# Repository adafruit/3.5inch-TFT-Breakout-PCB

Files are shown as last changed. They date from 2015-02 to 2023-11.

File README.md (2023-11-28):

# Adafruit 3.5 inch TFT LCD Display Breakout PCB

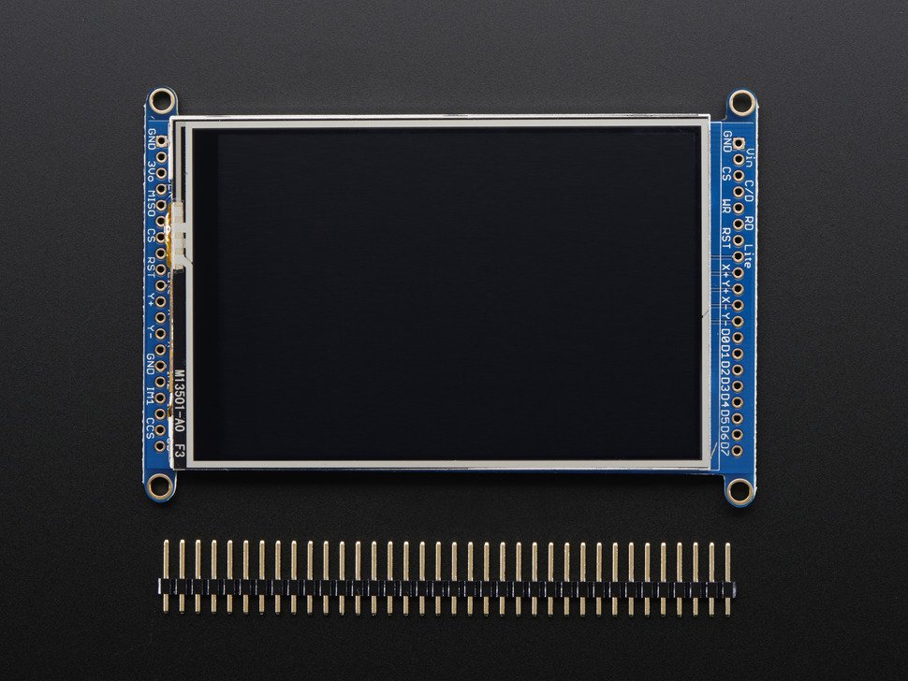
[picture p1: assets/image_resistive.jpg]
<a href="http://www.adafruit.com/products/2050"><br/>
Click here to purchase one from the Adafruit shop</a>

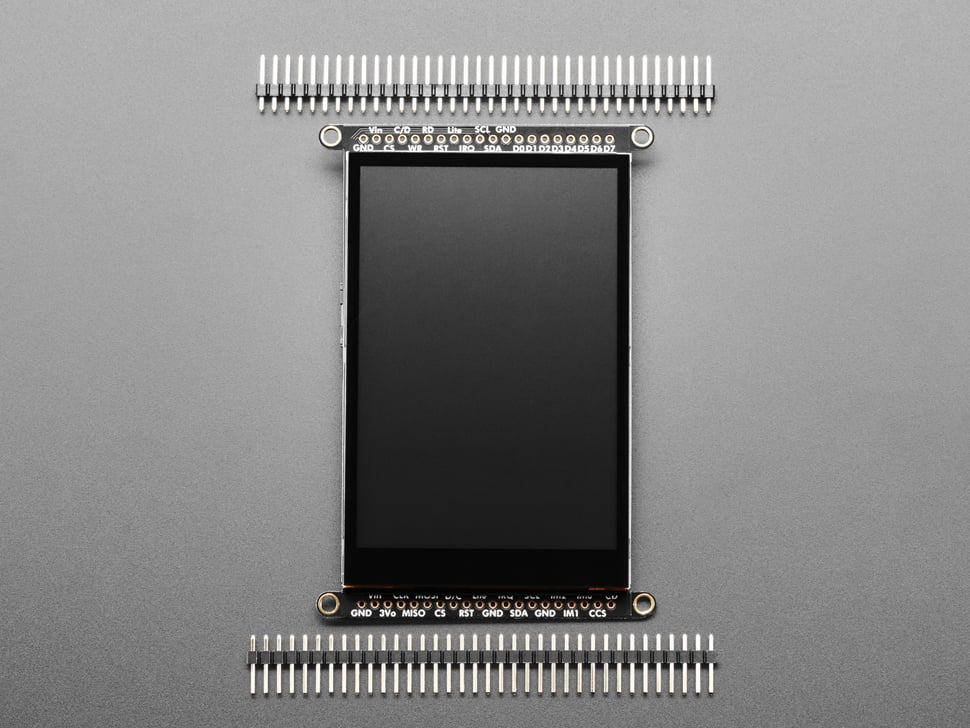
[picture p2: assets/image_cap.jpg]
<a href="http://www.adafruit.com/products/5846"><br/>
Click here to purchase one from the Adafruit shop</a>

Adafruit 3.5" 18-bit color TFT LCD display with microSD card breakout

This TFT display is big (3.5" diagonal) bright (6 white-LED backlight) and colorful! 480x320 pixels with individual RGB pixel control, this has way more resolution than a black and white 128x64 display, and double our 2.8" TFT. 

There are two version of this display: one has a resistive touchscreen attached to it and the other has a capacitive touchscreen attached.

This display has a controller built into it with RAM buffering, so that almost no work is done by the microcontroller. The display can be used in two modes: 8-bit or SPI. For 8-bit mode, you'll need 8 digital data lines and 4 or 5 digital control lines to read and write to the display (12 lines total). SPI mode requires only 5 pins total (SPI data in, data out, clock, select, and d/c) but is slower than 8-bit mode. In addition, 4 pins are required for the touch screen (2 digital, 2 analog) or you can purchase and use our resistive touchscreen controller (not included) to use I2C or SPI.

These are the Eagle CAD files for the Adafruit 3.5" 18-bit color TFT LCD display with microSD card breakout:
  ----> https://www.adafruit.com/products/2050

and the Adafruit 3.5" TFT 320x480 with Capacitive Touch Breakout Board - EYESPI
  ----> https://www.adafruit.com/products/5846

### License

Adafruit invests time and resources providing this open source design, please support Adafruit and open-source hardware by purchasing products from [Adafruit](https://www.adafruit.com)!

All text above must be included in any redistribution

Designed by Limor Fried/Ladyada for Adafruit Industries.
Creative Commons Attribution/Share-Alike, all text above must be included in any redistribution. 
See license.txt for additional information.

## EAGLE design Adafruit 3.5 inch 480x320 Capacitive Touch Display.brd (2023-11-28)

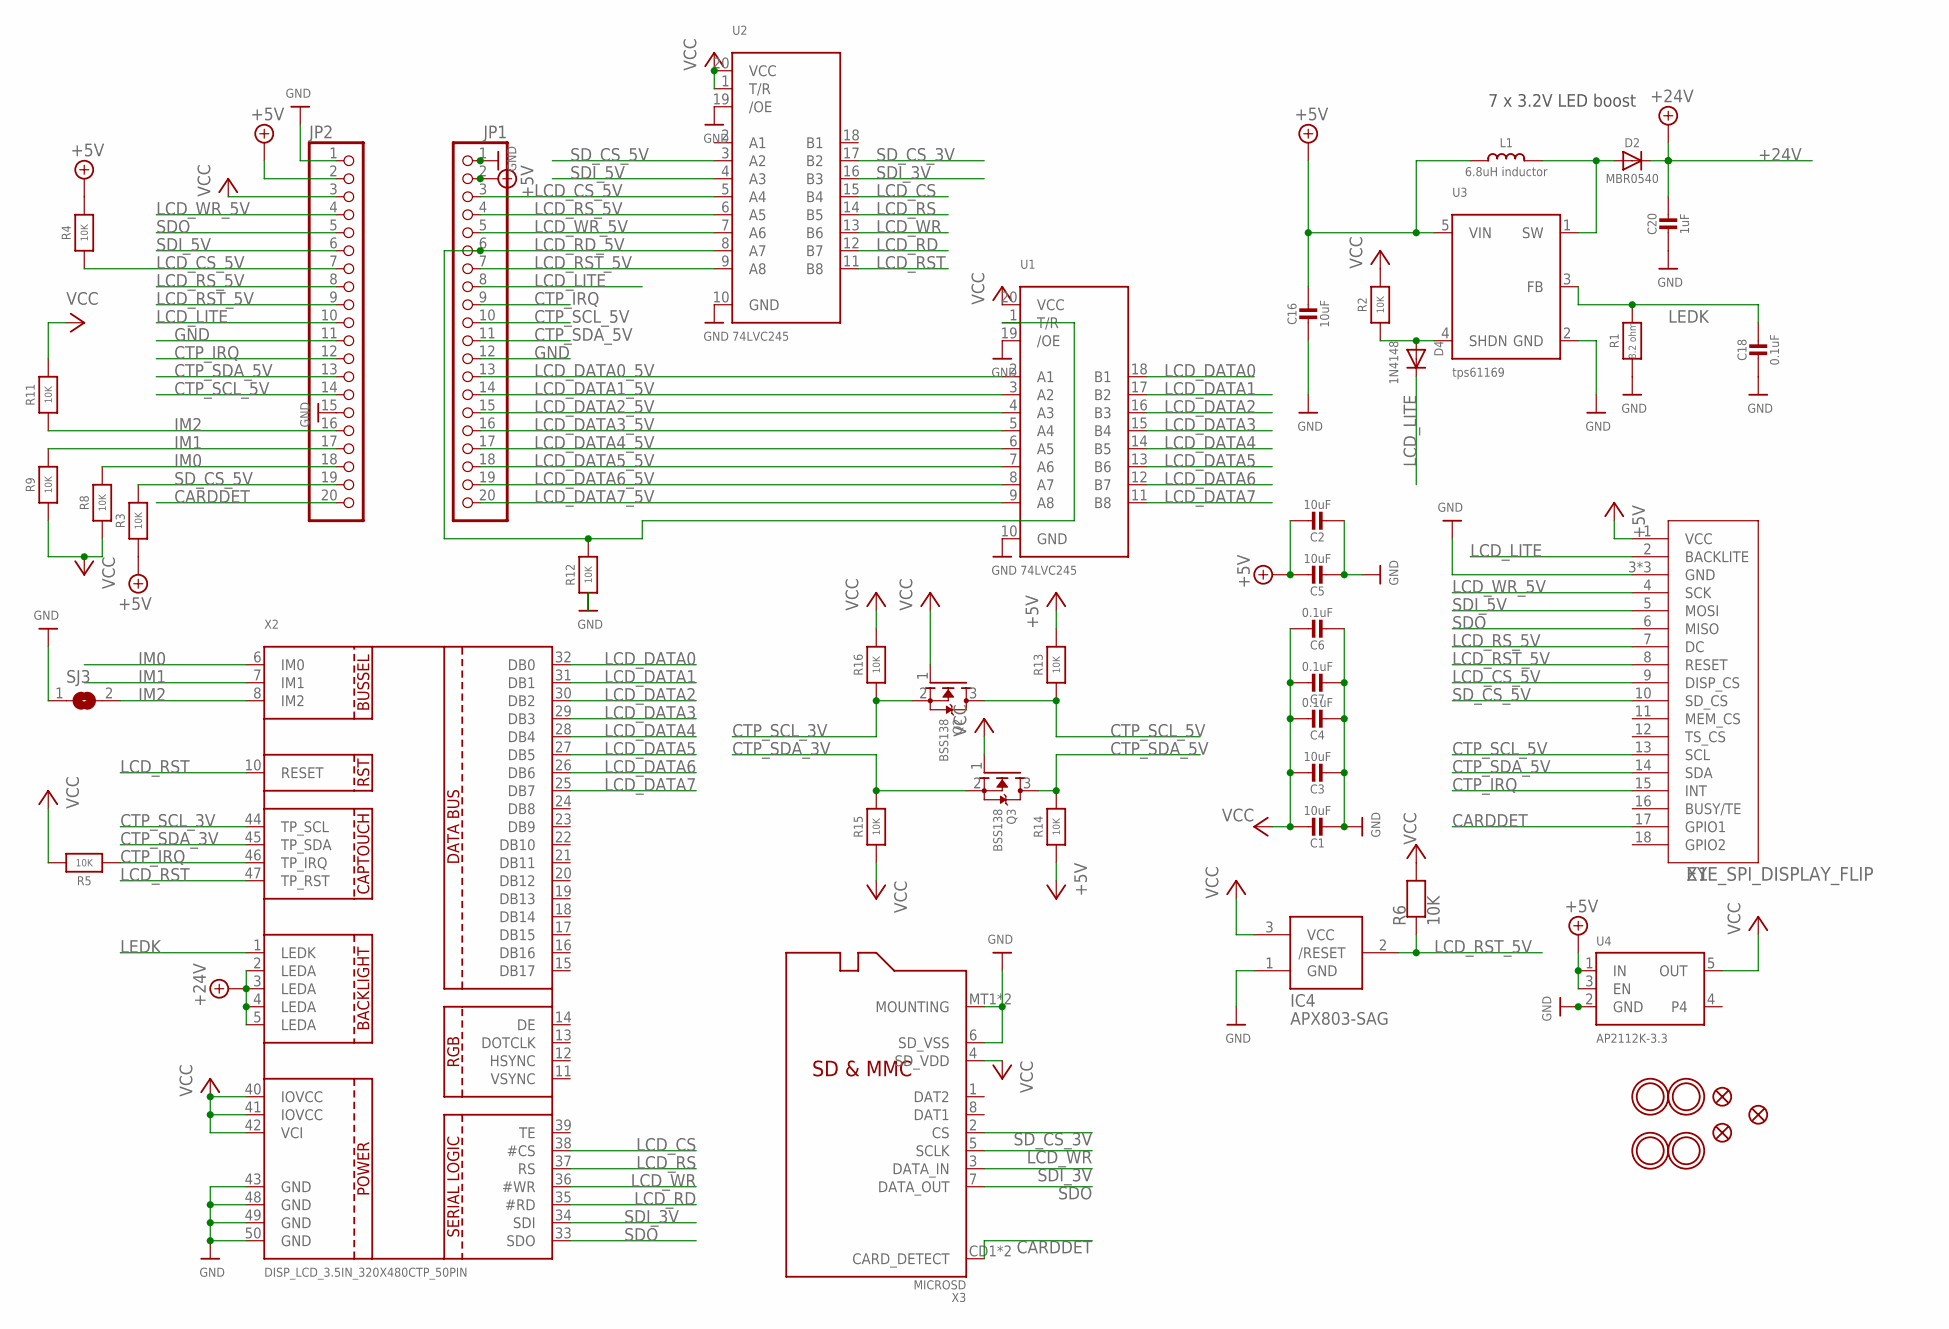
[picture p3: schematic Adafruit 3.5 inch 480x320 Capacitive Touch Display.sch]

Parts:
C1, C2, C3, C5, C16: 10uF; 0805-NO
C4, C6, C7, C18: 0.1uF; 0603-NO
C20: 1uF; 0805-NO
D2: MBR0540; SOD-123
D4: 1N4148; SOD-323F
IC4: APX803-SAG; SOT23
JP1, JP2: HEADER-1X20ROUND; 1X20_ROUND
L1: 6.8uH inductor; INDUCTOR_5X5MM_NR5040_NOTHERMALS
Q2, Q3: BSS138; SOT23-WIDE
R1: 8.2 ohm; 0603-NO
R2, R3, R4, R5, R6, R8, R9, R11, R12, R13, R14, R15, R16: 10K; 0603-NO
SJ3: SOLDERJUMPER; SOLDERJUMPER_ARROW_NOPASTE
U1, U2: 74LVC245; TSSOP20
U3: tps61169; SC70-5
U4: AP2112K-3.3; SOT23-5
U$7, U$15, U$16, U$17: MOUNTINGHOLE3.0THIN; MOUNTINGHOLE_3.0_PLATEDTHIN
U$9, U$11, U$23: FIDUCIAL_1MM
X1: EYE_SPI_DISPLAY_FLIP; EYE_SPI_DISPLAY_BOTCONTACT
X2: DISP_LCD_3.5IN_320X480CTP_50PIN; TFT_3.5IN_320X480_50PIN
X3: MICROSD

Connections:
+5V: C2.1, C5.1, C16.1, JP1.2, JP2.2, L1.P$1 (1), R3.1, R4.2, R13.2, R14.1, U3.5 (VIN), U4.1 (IN), U4.3 (EN), X1.1 (VCC)
+24V: C20.1, D2.C, X2.2 (LEDA), X2.3 (LEDA), X2.4 (LEDA), X2.5 (LEDA)
CARDDET: JP2.20, X1.17 (GPIO1), X3.CD1 (CARD_DETECT), X3.CD2 (CARD_DETECT)
CTP_IRQ: JP1.9, JP2.12, R5.1, X1.15 (INT), X2.46 (TP_IRQ)
CTP_SCL_3V: Q2.2 (S), R16.1, X2.44 (TP_SCL)
CTP_SCL_5V: JP1.10, JP2.14, Q2.3 (D), R13.1, X1.13 (SCL)
CTP_SDA_3V: Q3.2 (S), R15.2, X2.45 (TP_SDA)
CTP_SDA_5V: JP1.11, JP2.13, Q3.3 (D), R14.2, X1.14 (SDA)
GND: C1.2, C2.2, C3.2, C4.2, C5.2, C6.2, C7.2, C16.2, C18.2, C20.2, IC4.1 (GND), JP1.1, JP1.12, JP2.1, JP2.11, JP2.15, R1.1, R12.1, SJ3.1, U1.10 (GND), U1.19 (/OE), U2.10 (GND), U2.19 (/OE), U3.2 (GND), U4.2 (GND), X1.3 (GND), X1.SUPPORT1 (GND), X1.SUPPORT2 (GND), X2.43 (GND), X2.48 (GND), X2.49 (GND), X2.50 (GND), X3.6 (SD_VSS), X3.MT1 (MOUNTING), X3.MT2 (MOUNTING)
IM0: JP2.18, R8.2, X2.6 (IM0)
IM1: JP2.17, R9.2, X2.7 (IM1)
IM2: JP2.16, R11.1, SJ3.2, X2.8 (IM2)
LCD_CS: U2.15 (B4), X2.38 (#CS)
LCD_CS_5V: JP1.3, JP2.7, R4.1, U2.5 (A4), X1.9 (DISP_CS)
LCD_DATA0: U1.18 (B1), X2.32 (DB0)
LCD_DATA0_5V: JP1.13, U1.2 (A1)
LCD_DATA1: U1.17 (B2), X2.31 (DB1)
LCD_DATA1_5V: JP1.14, U1.3 (A2)
LCD_DATA2: U1.16 (B3), X2.30 (DB2)
LCD_DATA2_5V: JP1.15, U1.4 (A3)
LCD_DATA3: U1.15 (B4), X2.29 (DB3)
LCD_DATA3_5V: JP1.16, U1.5 (A4)
LCD_DATA4: U1.14 (B5), X2.28 (DB4)
LCD_DATA4_5V: JP1.17, U1.6 (A5)
LCD_DATA5: U1.13 (B6), X2.27 (DB5)
LCD_DATA5_5V: JP1.18, U1.7 (A6)
LCD_DATA6: U1.12 (B7), X2.26 (DB6)
LCD_DATA6_5V: JP1.19, U1.8 (A7)
LCD_DATA7: U1.11 (B8), X2.25 (DB7)
LCD_DATA7_5V: JP1.20, U1.9 (A8)
LCD_LITE: D4.C, JP1.8, JP2.10, X1.2 (BACKLITE)
LCD_RD: U2.12 (B7), X2.35 (#RD)
LCD_RD_5V: JP1.6, R12.2, U1.1 (T/R), U2.8 (A7)
LCD_RS: U2.14 (B5), X2.37 (RS)
LCD_RST: U2.11 (B8), X2.10 (RESET), X2.47 (TP_RST)
LCD_RST_5V: IC4.2 (/RESET), JP1.7, JP2.9, R6.1, U2.9 (A8), X1.8 (RESET)
LCD_RS_5V: JP1.4, JP2.8, U2.6 (A5), X1.7 (DC)
LCD_WR: U2.13 (B6), X2.36 (#WR), X3.5 (SCLK)
LCD_WR_5V: JP1.5, JP2.4, U2.7 (A6), X1.4 (SCK)
LEDK: C18.1, R1.2, U3.3 (FB), X2.1 (LEDK)
unnamed: D2.A, L1.P$2 (2), U3.1 (SW)
SDI_3V: U2.16 (B3), X2.34 (SDI), X3.3 (DATA_IN)
SDI_5V: JP2.6, U2.4 (A3), X1.5 (MOSI)
SDO: JP2.5, X1.6 (MISO), X2.33 (SDO), X3.7 (DATA_OUT)
SD_CS_3V: U2.17 (B2), X3.2 (CS)
SD_CS_5V: JP2.19, R3.2, U2.3 (A2), X1.10 (SD_CS)
SHDN: D4.A, R2.1, U3.4 (SHDN)
VCC: C1.1, C3.1, C4.1, C6.1, C7.1, IC4.3 (VCC), JP2.3, Q2.1 (G), Q3.1 (G), R2.2, R5.2, R6.2, R8.1, R9.1, R11.2, R15.1, R16.2, U1.20 (VCC), U2.1 (T/R), U2.20 (VCC), U4.5 (OUT), X2.40 (IOVCC), X2.41 (IOVCC), X2.42 (VCI), X3.4 (SD_VDD)

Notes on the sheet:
7 x 3.2V LED boost

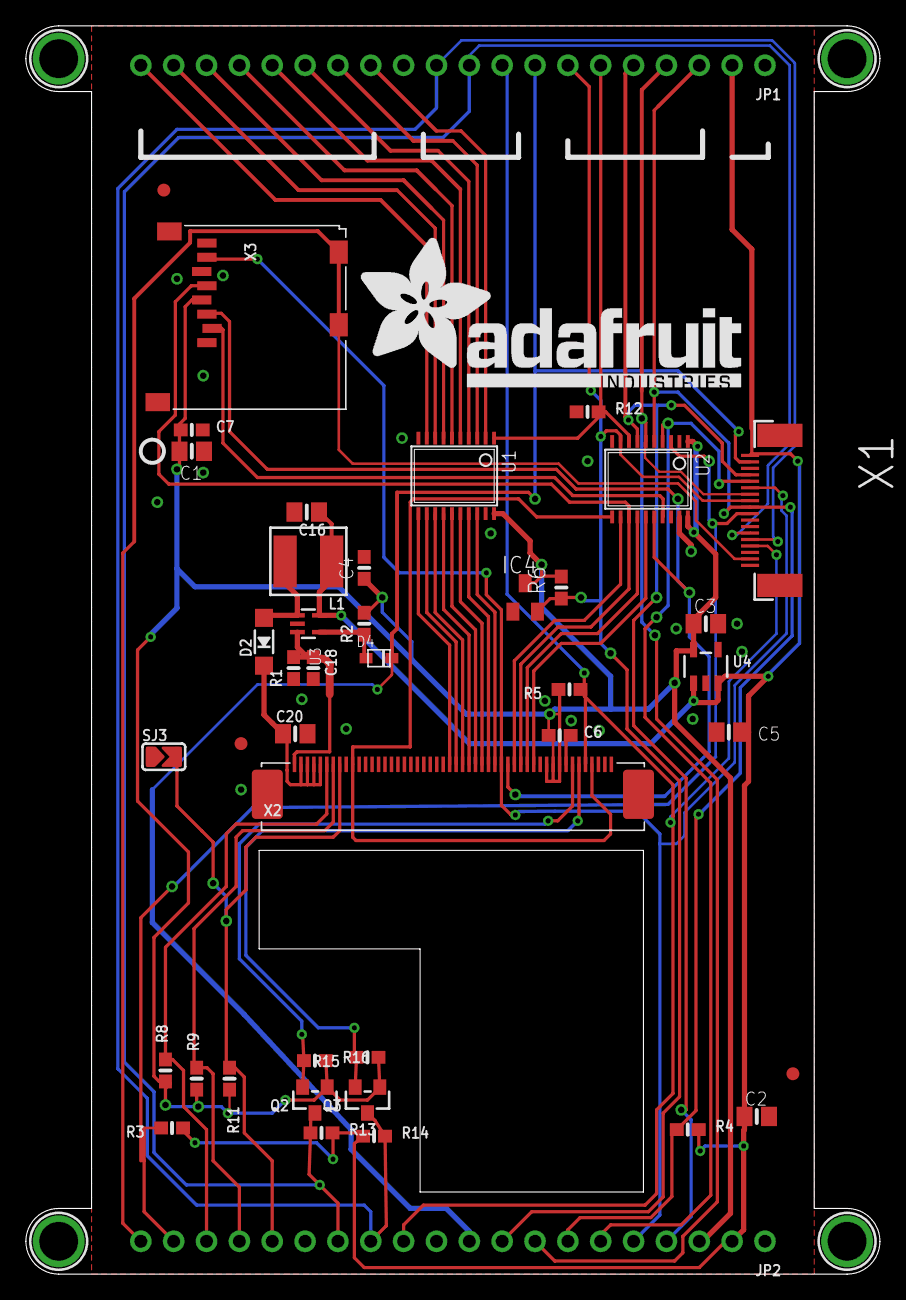
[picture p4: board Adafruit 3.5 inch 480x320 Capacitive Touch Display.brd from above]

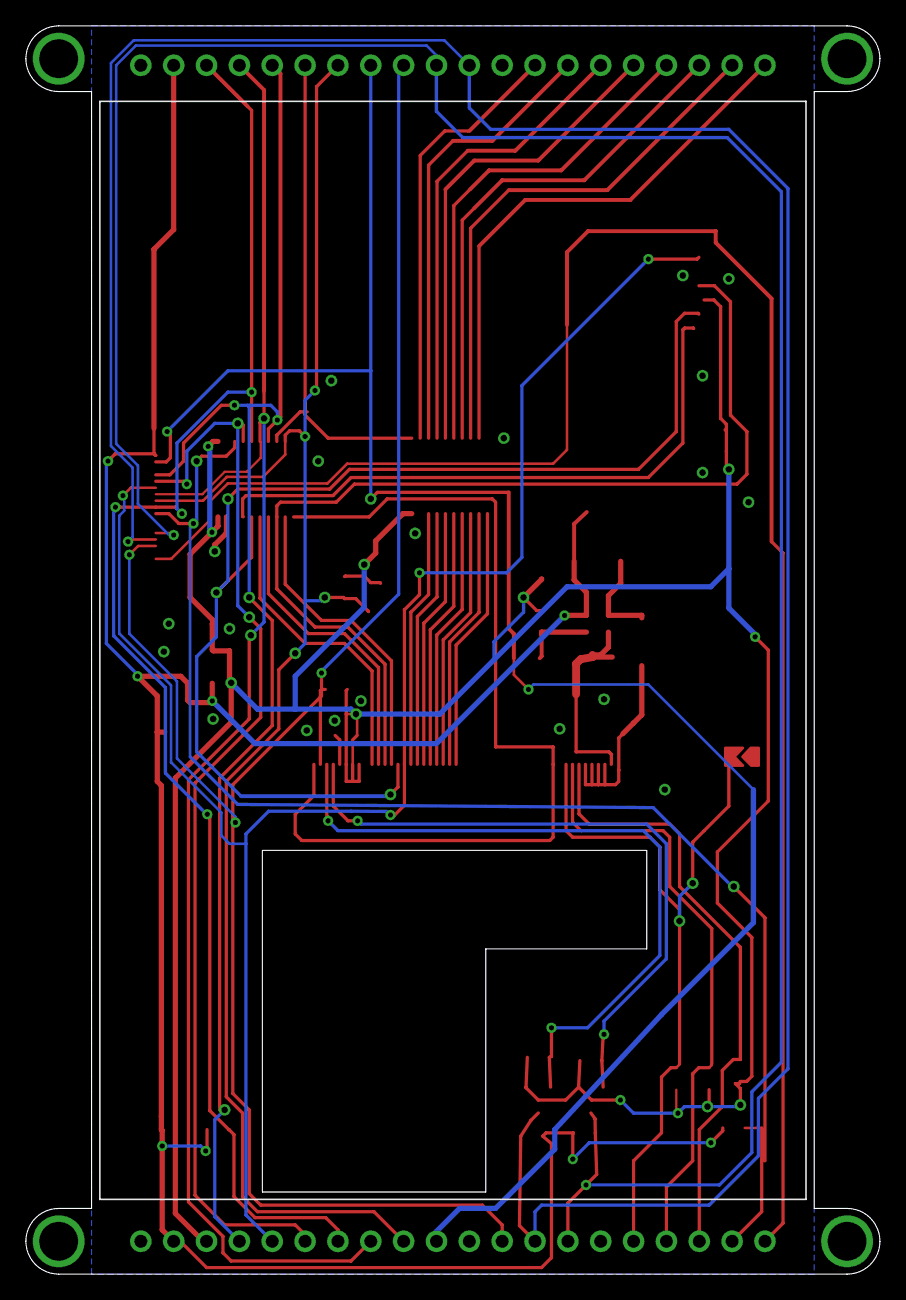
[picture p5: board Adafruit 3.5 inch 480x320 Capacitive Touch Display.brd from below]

Board: 2 copper layers, 66.0 x 96.5 mm, 143 parts (41 on the bottom side), 48 nets.

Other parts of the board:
PLABEL0: PLABEL0
PLABEL1: PLABEL1
PLABEL2: PLABEL2
PLABEL3: PLABEL3
PLABEL4: PLABEL4
PLABEL5: PLABEL5
PLABEL6: PLABEL6
PLABEL7: PLABEL7
PLABEL8: PLABEL8
PLABEL9: PLABEL9
PLABEL10: PLABEL10
PLABEL11: PLABEL11
PLABEL12: PLABEL12
PLABEL13: PLABEL13
PLABEL14: PLABEL14
PLABEL15: PLABEL15
PLABEL16: PLABEL16
PLABEL17: PLABEL17
PLABEL18: PLABEL18
PLABEL19: PLABEL19
PLABEL20: PLABEL20
PLABEL21: PLABEL21
PLABEL22: PLABEL22
PLABEL23: PLABEL23
PLABEL24: PLABEL24
PLABEL25: PLABEL25
PLABEL26: PLABEL26
PLABEL27: PLABEL27
PLABEL28: PLABEL28
PLABEL29: PLABEL29
PLABEL30: PLABEL30
PLABEL31: PLABEL31
PLABEL32: PLABEL32
PLABEL33: PLABEL33
PLABEL34: PLABEL34
PLABEL35: PLABEL35
PLABEL36: PLABEL36
PLABEL37: PLABEL37
PLABEL38: PLABEL38
PLABEL39: PLABEL39
PLABEL40: PLABEL40
PLABEL41: PLABEL41
PLABEL42: PLABEL42
PLABEL43: PLABEL43
PLABEL44: PLABEL44
PLABEL45: PLABEL45
PLABEL46: PLABEL46
PLABEL47: PLABEL47
PLABEL48: PLABEL48
PLABEL49: PLABEL49
PLABEL50: PLABEL50
PLABEL51: PLABEL51
PLABEL52: PLABEL52
PLABEL53: PLABEL53
PLABEL54: PLABEL54
PLABEL55: PLABEL55
PLABEL56: PLABEL56
PLABEL57: PLABEL57
PLABEL58: PLABEL58
PLABEL59: PLABEL59
PLABEL60: PLABEL60
PLABEL61: PLABEL61
PLABEL62: PLABEL62
PLABEL63: PLABEL63
PLABEL64: PLABEL64
PLABEL65: PLABEL65
PLABEL66: PLABEL66
PLABEL67: PLABEL67
PLABEL68: PLABEL68
PLABEL69: PLABEL69
PLABEL70: PLABEL70
PLABEL71: PLABEL71
PLABEL72: PLABEL72
PLABEL73: PLABEL73
PLABEL74: PLABEL74
PLABEL75: PLABEL75
PLABEL76: PLABEL76
PLABEL77: PLABEL77
PLABEL78: PLABEL78
PLABEL79: PLABEL79
PLABEL80: PLABEL80
PLABEL81: PLABEL81
PLABEL82: PLABEL82
PLABEL83: PLABEL83
PLABEL84: PLABEL84
PLABEL85: PLABEL85
PLABEL86: PLABEL86
PLABEL87: PLABEL87
PLABEL88: PLABEL88
PLABEL89: PLABEL89
PLABEL90: PLABEL90
PLABEL91: PLABEL91
PLABEL92: PLABEL92
PLABEL93: PLABEL93
U$19: ADAFRUIT_TEXT_30MM
U$31: PCBFEAT-REV-040

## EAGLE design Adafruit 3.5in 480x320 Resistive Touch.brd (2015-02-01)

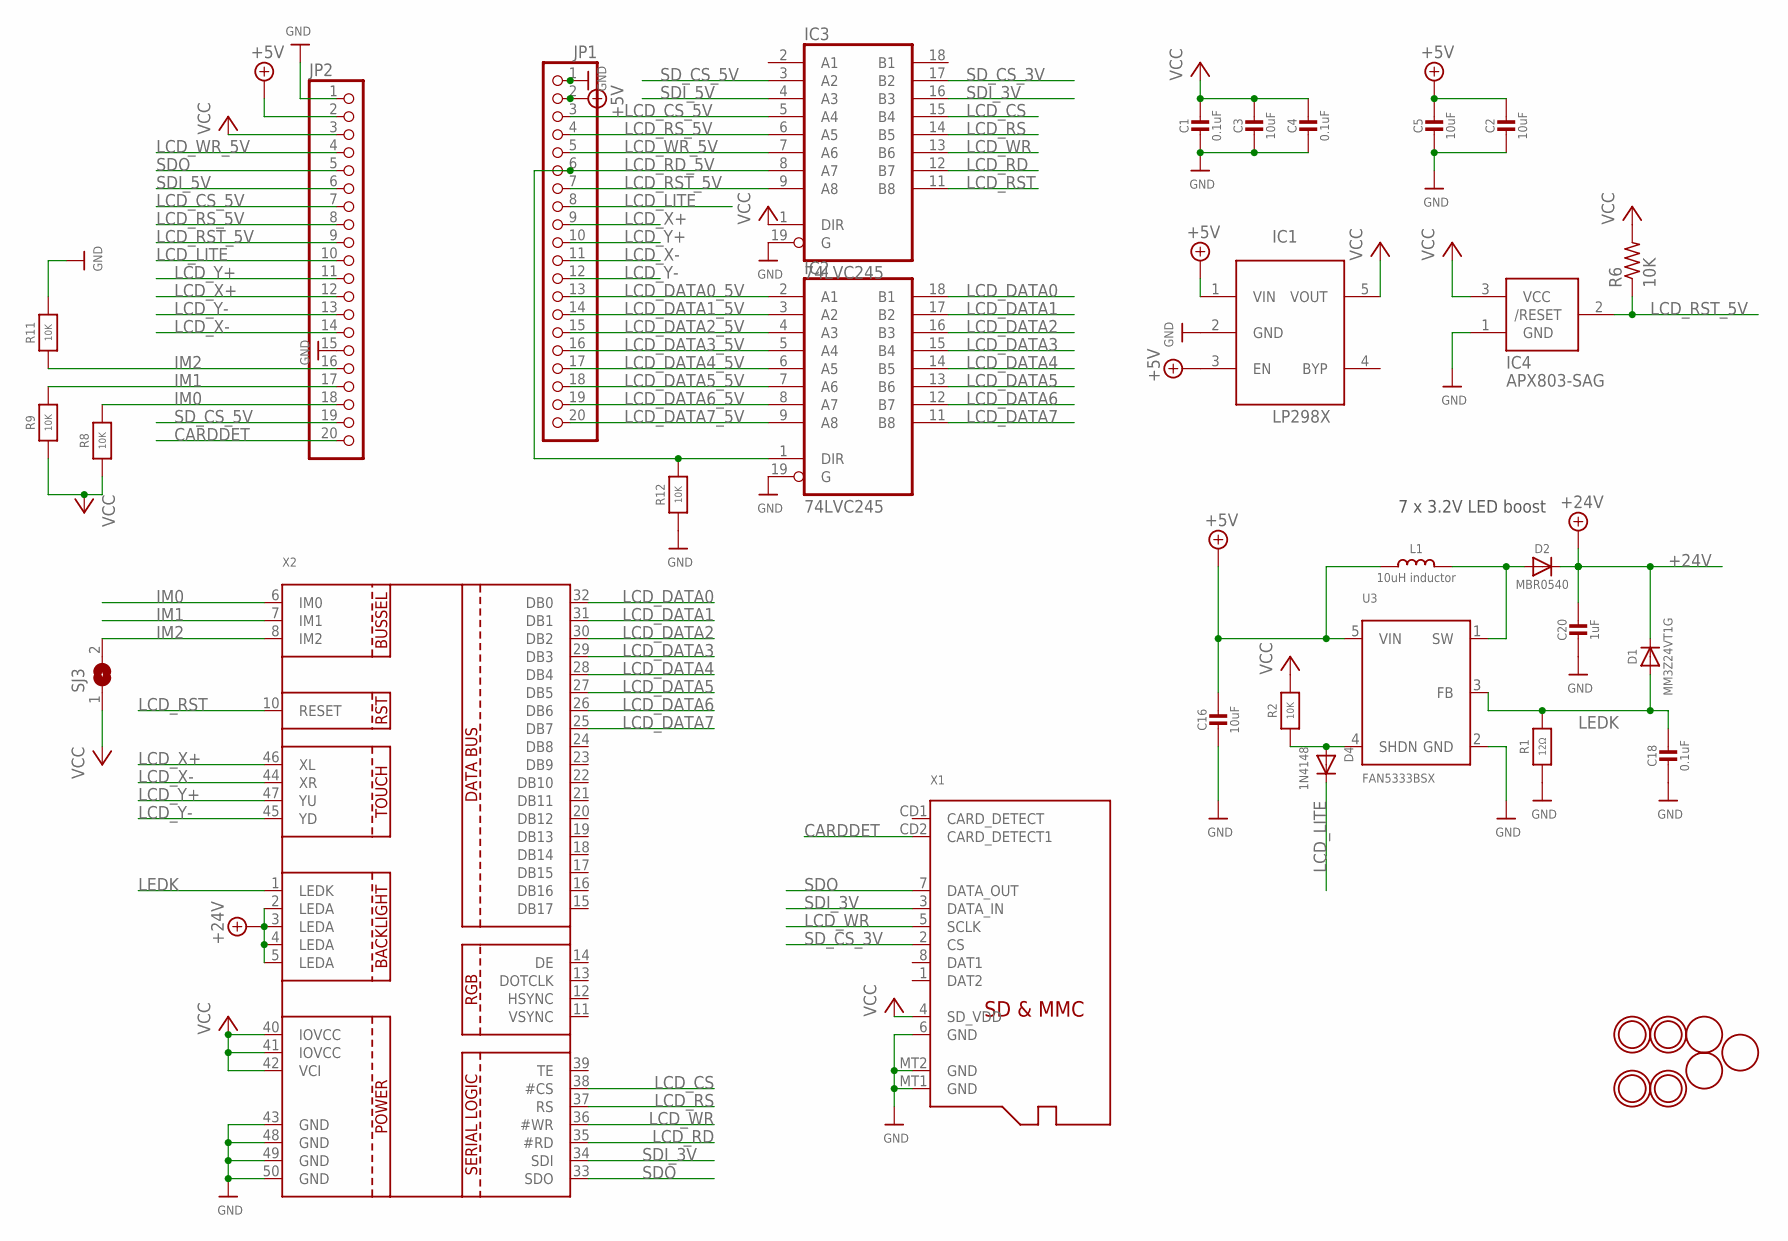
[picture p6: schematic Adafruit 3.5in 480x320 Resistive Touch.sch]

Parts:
C1, C4, C18: 0.1uF; 0805-NO
C2, C3, C5: 10uF; 0805-NO
C16: 10uF; _0805MP
C20: 1uF; 0805-NO
D1: MM3Z24VT1G; SMADIODE
D2: MBR0540; SOD-123
D4: 1N4148; SOD-323F
IC1: MIC5225-3.3; SOT23-5L
IC2, IC3: 74LVC245; SO20W
IC4: APX803-SAG; SOT23
JP1, JP2: HEADER-1X20ROUND; 1X20_ROUND
L1: 10uH inductor; INDUCTOR_5X5MM_NR5040_NOTHERMALS
R1: 12Ω; _0805MP
R2, R8, R9, R11, R12: 10K; 0805-NO
R6: 10K; R0805
SJ3: SOLDERJUMPER; SOLDERJUMPER_ARROW_NOPASTE
U3: FAN5333BSX; SOT23-5@1
U$7, U$15, U$16, U$17: MOUNTINGHOLE3.0THIN; MOUNTINGHOLE_3.0_PLATEDTHIN
U$9, U$11, U$23: FIDUCIAL; FIDUCIAL_1MM
X1: MICROSD
X2: DISP_LCD_3.5IN_320X480_50PIN; TFT_3.5IN_320X480_50PIN

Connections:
+5V: C2.1, C5.1, C16.1, IC1.1 (VIN), IC1.3 (EN), JP1.2, JP2.2, L1.P$1 (1), U3.5 (VIN)
+24V: C20.1, D1.C, D2.C, X2.2 (LEDA), X2.3 (LEDA), X2.4 (LEDA), X2.5 (LEDA)
CARDDET: JP2.20, X1.CD2 (CARD_DETECT1)
GND: C1.2, C2.2, C3.2, C4.2, C5.2, C16.2, C18.2, C20.2, IC1.2 (GND), IC2.10 (GND), IC2.19 (G), IC3.10 (GND), IC3.19 (G), IC4.1 (GND), JP1.1, JP2.1, JP2.15, R1.1, R11.2, R12.1, U3.2 (GND), X1.6 (GND), X1.MT1 (GND), X1.MT2 (GND), X2.43 (GND), X2.48 (GND), X2.49 (GND), X2.50 (GND)
IM0: JP2.18, R8.2, X2.6 (IM0)
IM1: JP2.17, R9.2, X2.7 (IM1)
IM2: JP2.16, R11.1, SJ3.2, X2.8 (IM2)
LCD_CS: IC3.15 (B4), X2.38 (#CS)
LCD_CS_5V: IC3.5 (A4), JP1.3, JP2.7
LCD_DATA0: IC2.18 (B1), X2.32 (DB0)
LCD_DATA0_5V: IC2.2 (A1), JP1.13
LCD_DATA1: IC2.17 (B2), X2.31 (DB1)
LCD_DATA1_5V: IC2.3 (A2), JP1.14
LCD_DATA2: IC2.16 (B3), X2.30 (DB2)
LCD_DATA2_5V: IC2.4 (A3), JP1.15
LCD_DATA3: IC2.15 (B4), X2.29 (DB3)
LCD_DATA3_5V: IC2.5 (A4), JP1.16
LCD_DATA4: IC2.14 (B5), X2.28 (DB4)
LCD_DATA4_5V: IC2.6 (A5), JP1.17
LCD_DATA5: IC2.13 (B6), X2.27 (DB5)
LCD_DATA5_5V: IC2.7 (A6), JP1.18
LCD_DATA6: IC2.12 (B7), X2.26 (DB6)
LCD_DATA6_5V: IC2.8 (A7), JP1.19
LCD_DATA7: IC2.11 (B8), X2.25 (DB7)
LCD_DATA7_5V: IC2.9 (A8), JP1.20
LCD_LITE: D4.C, JP1.8, JP2.10
LCD_RD: IC3.12 (B7), X2.35 (#RD)
LCD_RD_5V: IC2.1 (DIR), IC3.8 (A7), JP1.6, R12.2
LCD_RS: IC3.14 (B5), X2.37 (RS)
LCD_RST: IC3.11 (B8), X2.10 (RESET)
LCD_RST_5V: IC3.9 (A8), IC4.2 (/RESET), JP1.7, JP2.9, R6.1
LCD_RS_5V: IC3.6 (A5), JP1.4, JP2.8
LCD_WR: IC3.13 (B6), X1.5 (SCLK), X2.36 (#WR)
LCD_WR_5V: IC3.7 (A6), JP1.5, JP2.4
LCD_X+: JP1.9, JP2.12, X2.46 (XL)
LCD_X-: JP1.11, JP2.14, X2.44 (XR)
LCD_Y+: JP1.10, JP2.11, X2.47 (YU)
LCD_Y-: JP1.12, JP2.13, X2.45 (YD)
LEDK: C18.1, D1.A, R1.2, U3.3 (FB), X2.1 (LEDK)
unnamed: D2.A, L1.P$2 (2), U3.1 (SW)
SDI_3V: IC3.16 (B3), X1.3 (DATA_IN), X2.34 (SDI)
SDI_5V: IC3.4 (A3), JP2.6
SDO: JP2.5, X1.7 (DATA_OUT), X2.33 (SDO)
SD_CS_3V: IC3.17 (B2), X1.2 (CS)
SD_CS_5V: IC3.3 (A2), JP2.19
SHDN: D4.A, R2.1, U3.4 (SHDN)
VCC: C1.1, C3.1, C4.1, IC1.5 (VOUT), IC2.20 (VCC), IC3.1 (DIR), IC3.20 (VCC), IC4.3 (VCC), JP2.3, R2.2, R6.2, R8.1, R9.1, SJ3.1, X1.4 (SD_VDD), X2.40 (IOVCC), X2.41 (IOVCC), X2.42 (VCI)

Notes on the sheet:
7 x 3.2V LED boost

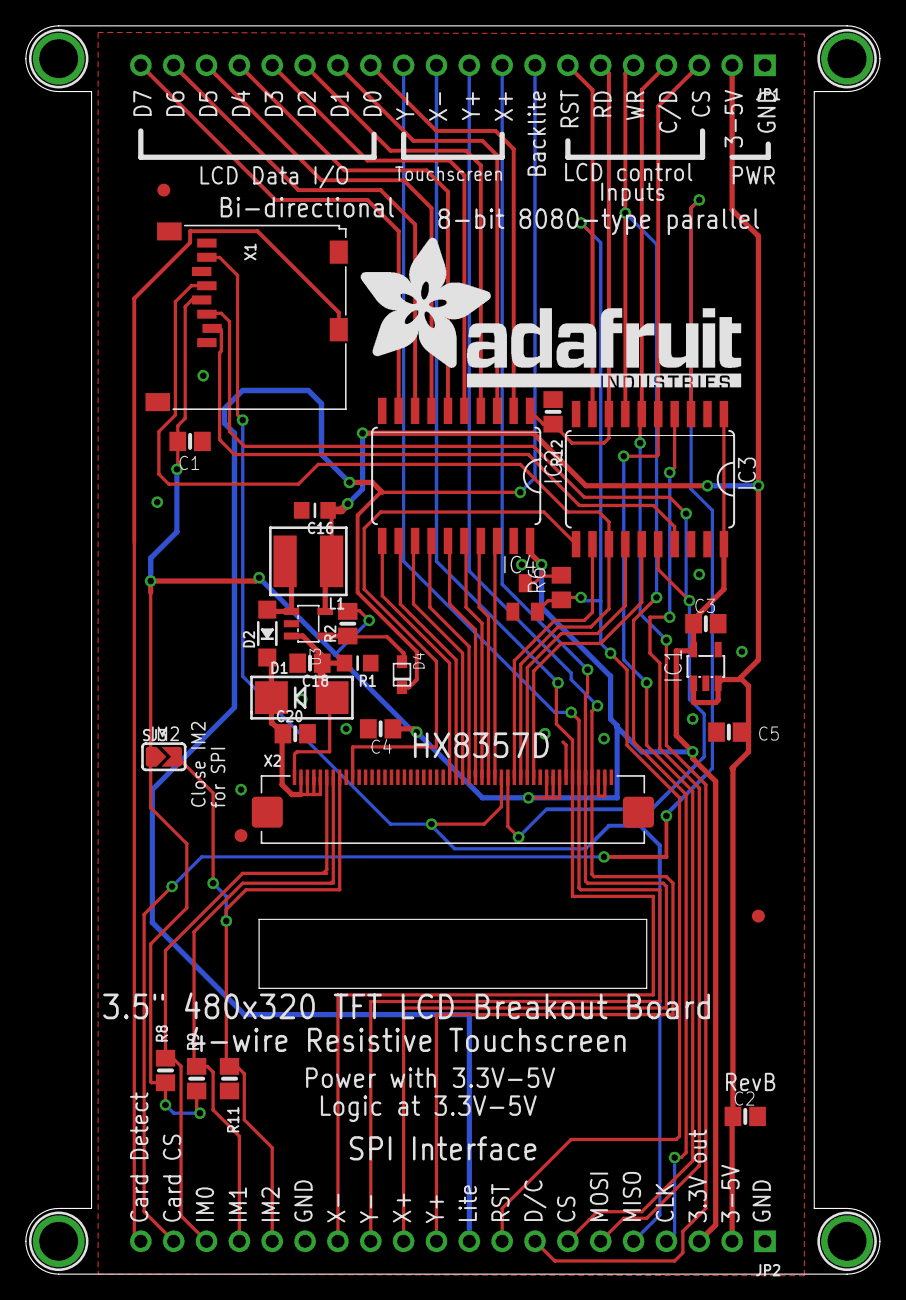
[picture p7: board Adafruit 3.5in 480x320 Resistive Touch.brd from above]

Board: 2 copper layers, 66.0 x 96.5 mm, 37 parts (1 on the bottom side), 47 nets.

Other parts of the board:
U$19: ADAFRUIT_TEXT_30MM
